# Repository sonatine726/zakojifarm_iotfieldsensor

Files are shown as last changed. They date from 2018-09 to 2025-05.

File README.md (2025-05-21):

# 座光寺農園の田んぼの環境センシングIoT機器

# 機能仕様

1. 設置した田んぼの気温、気圧、水位、GPS座標、バッテリー残量といったデータを定期的に計測する
2. 1で計測したデータをLTEでWEBサーバにアップロードする
3. 間欠動作でバッテリー交換無しで１シーズンの長期間駆動を実現する
4. 2のデータはWEBブラウザやスマートフォンアプリで、時系列順の参照や統計処理を可能にする
5. 4のデータに対してメールやMQTTによるアラート通知を可能にする
6. 自動水門開閉機能といった将来的な機能拡張が可能な機構や設計にする

# 成果物の形式と保管場所
## ハードウェア
### 機構
CADデータは Fusion360で作成。保管はFusion Team のクラウドストレージを使用する。
それ以外のデータは本リポジトリに保管。

### 基板
基板データはKiCadで作成。保管は本リポジトリ。

Pcbディレクトリ： 各基板のKiCadデータ

Fritzingディレクトリ： 試作用のFritzingデータ

## ソフトウェア
### クライアント(IoT機器)
本リポジトリに保管。

### サーバ
WEBサービスごとに専用のリポジトリを作って保管

### スマートフォンアプリ
アプリケーションごとに専用のリポジトリを作って保管

# 各成果物のイメージ
## 基板

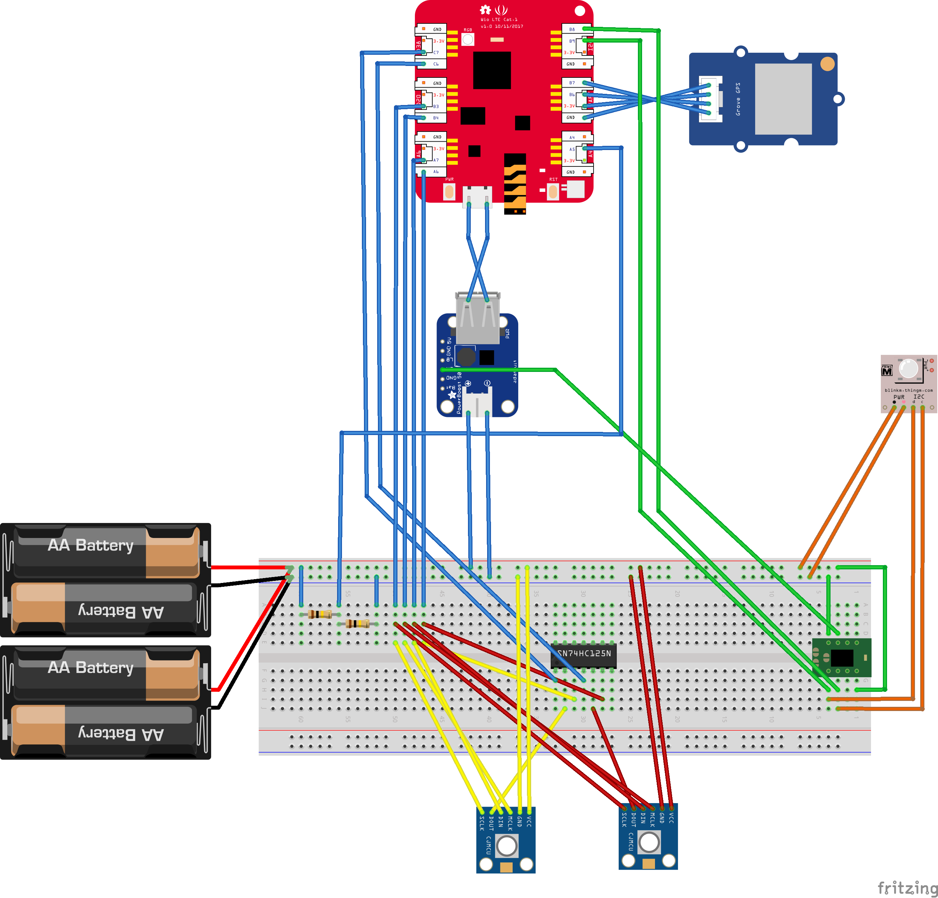
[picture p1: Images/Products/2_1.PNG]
試作回路

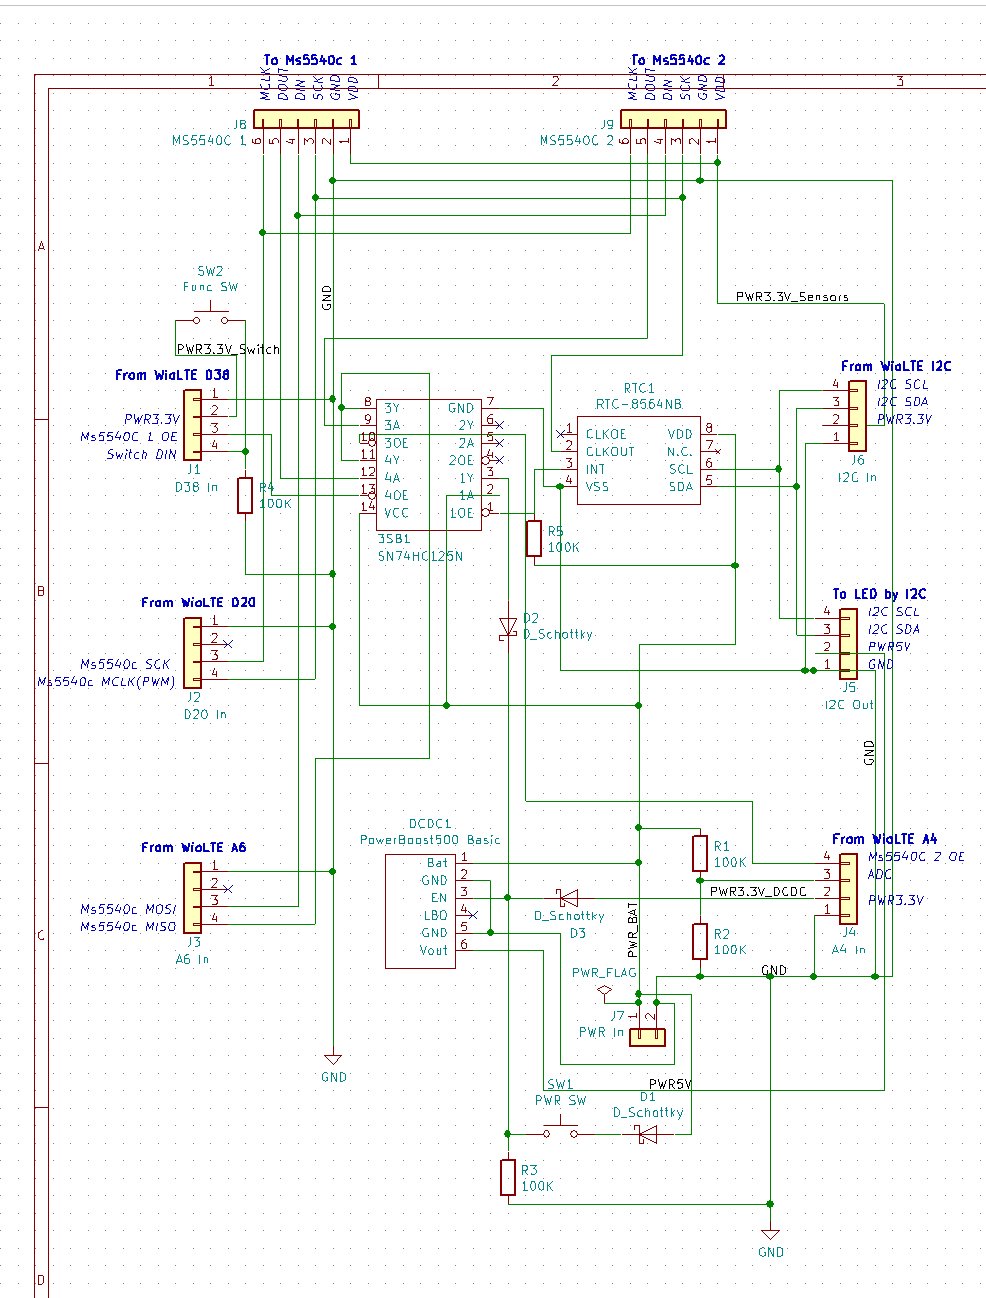
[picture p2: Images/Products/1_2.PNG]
回路基板

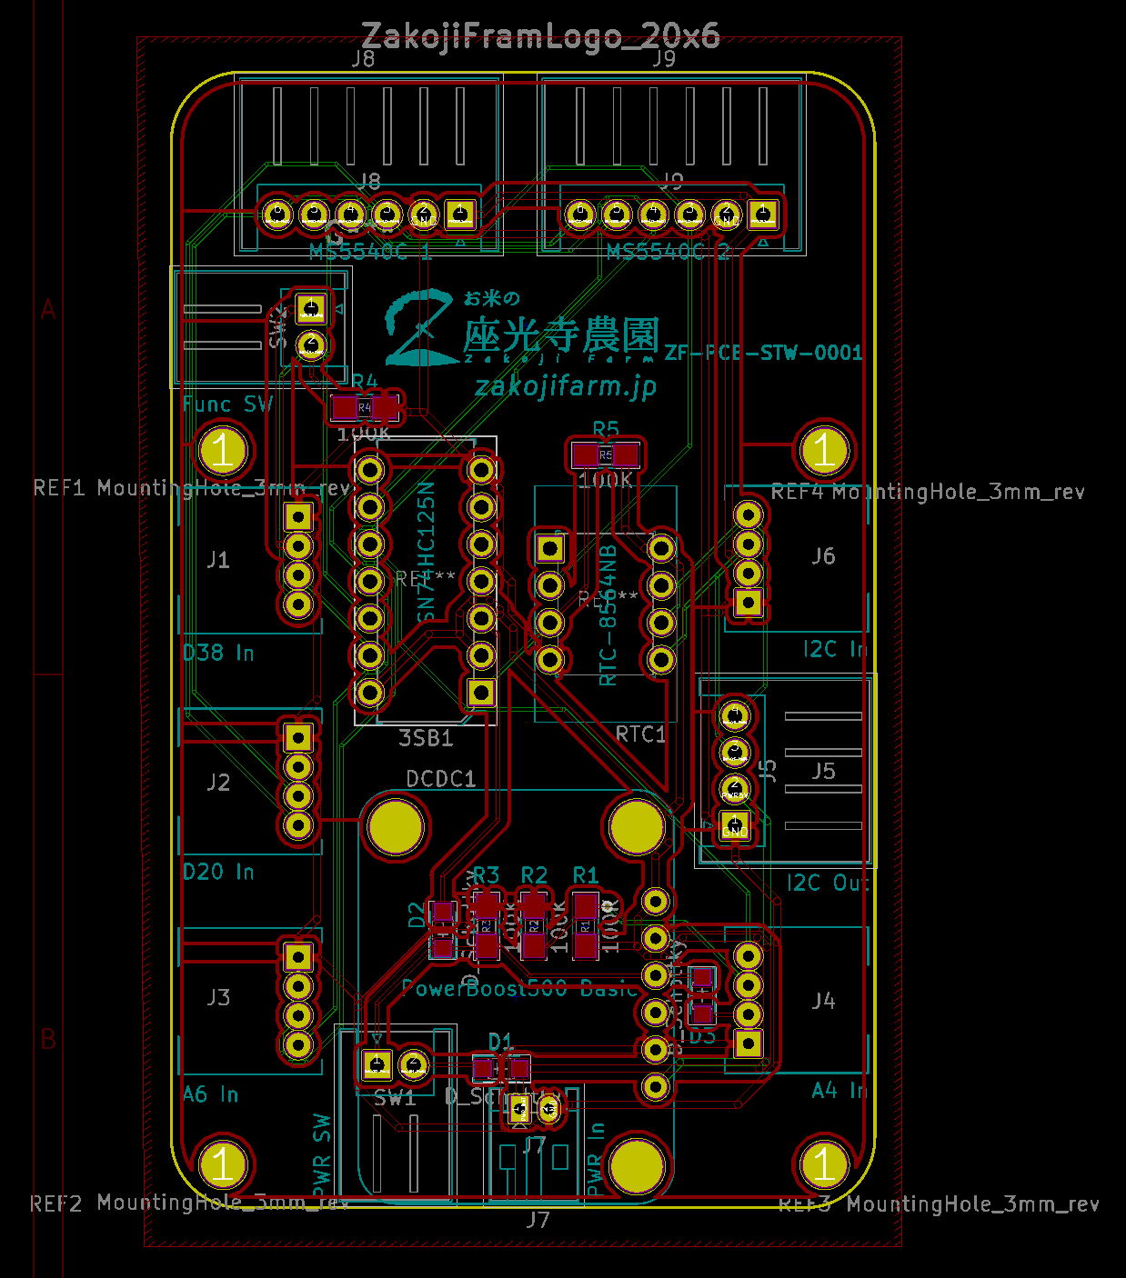
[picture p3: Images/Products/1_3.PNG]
アートワーク

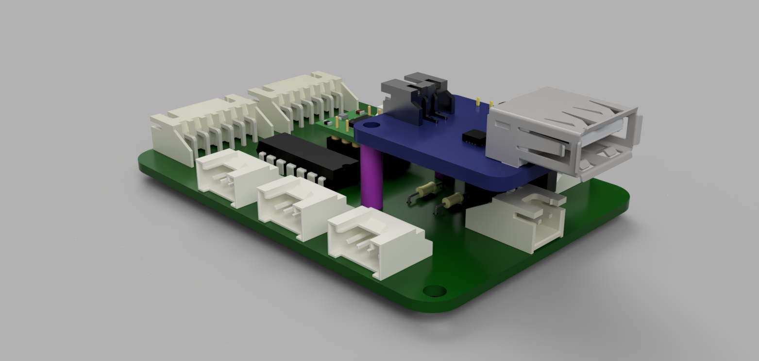
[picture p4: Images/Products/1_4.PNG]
CGイメージ

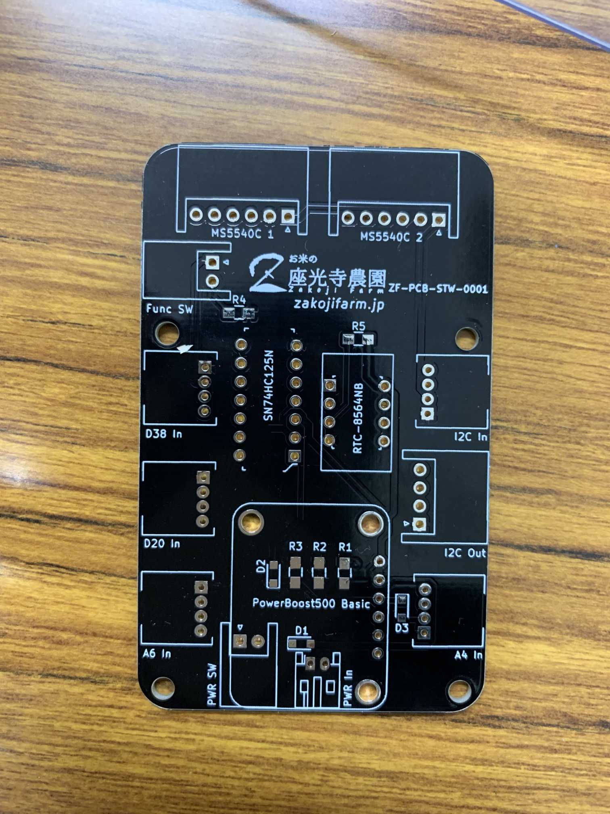
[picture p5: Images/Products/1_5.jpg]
成果物1

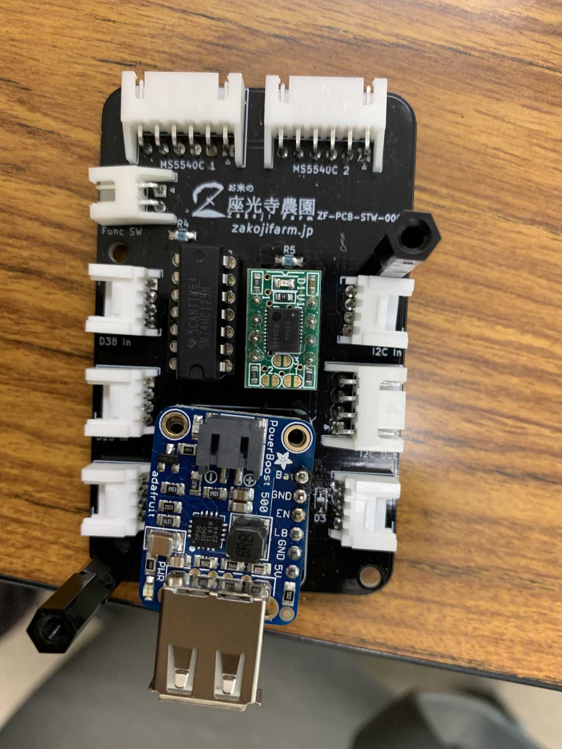
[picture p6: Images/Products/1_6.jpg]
成果物2


## 機構
### フラグシップモデル
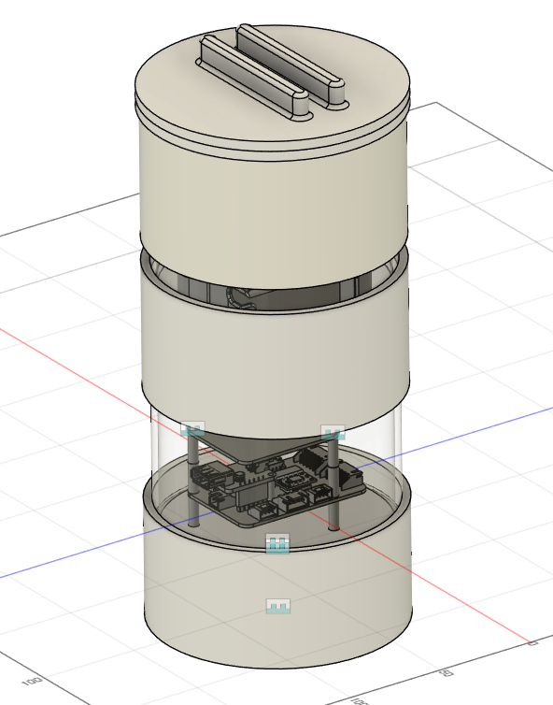
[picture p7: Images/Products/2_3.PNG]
機構1-1

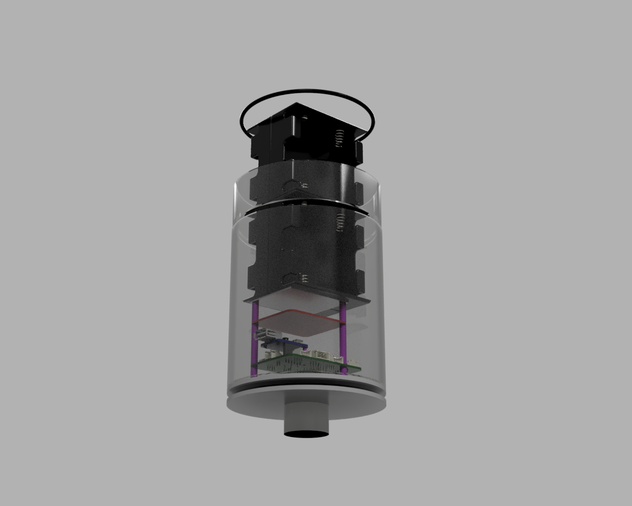
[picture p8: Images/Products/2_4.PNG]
機構1-2

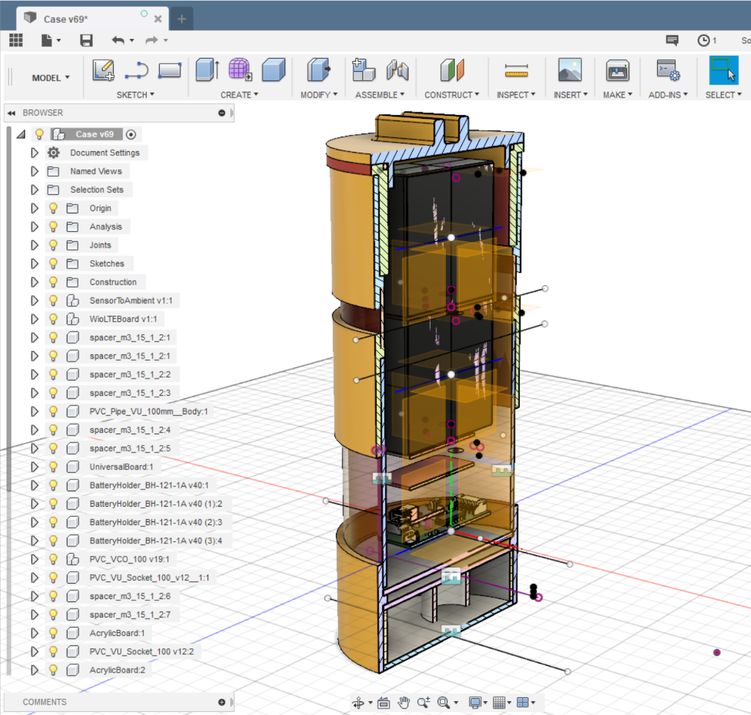
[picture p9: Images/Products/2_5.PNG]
機構1-3

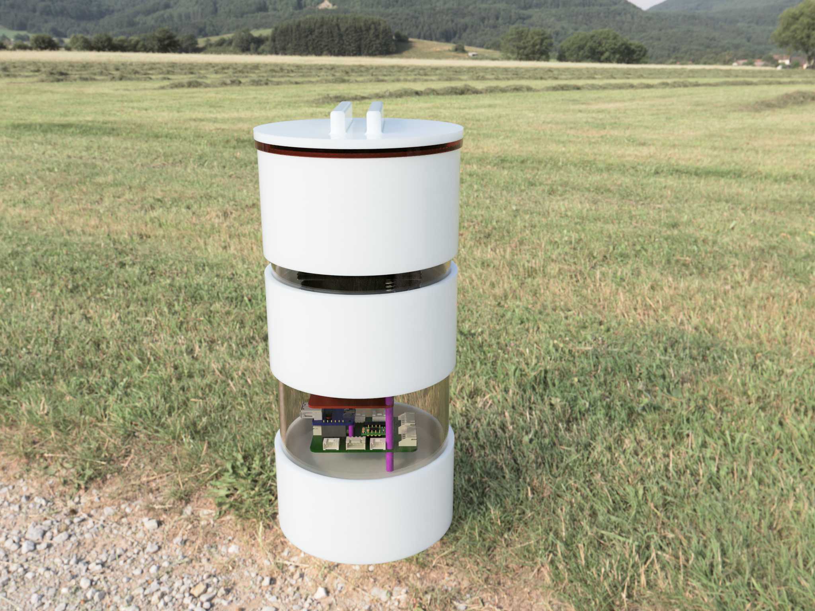
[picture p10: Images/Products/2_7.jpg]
機構1-4

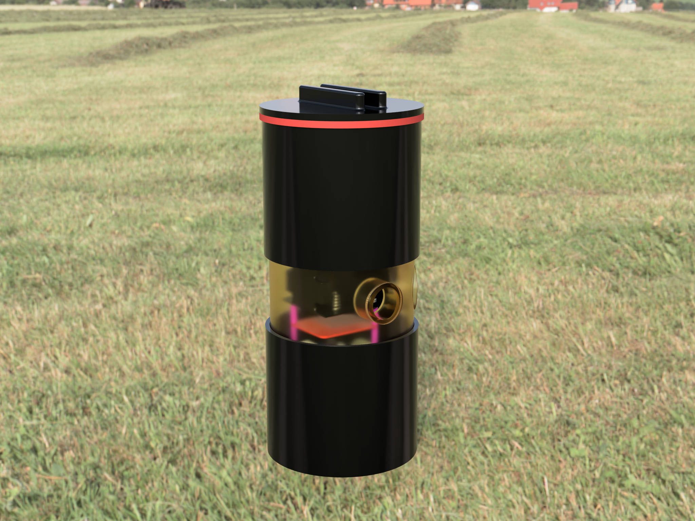
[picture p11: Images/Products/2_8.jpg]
機構1-5


### エントリーモデル
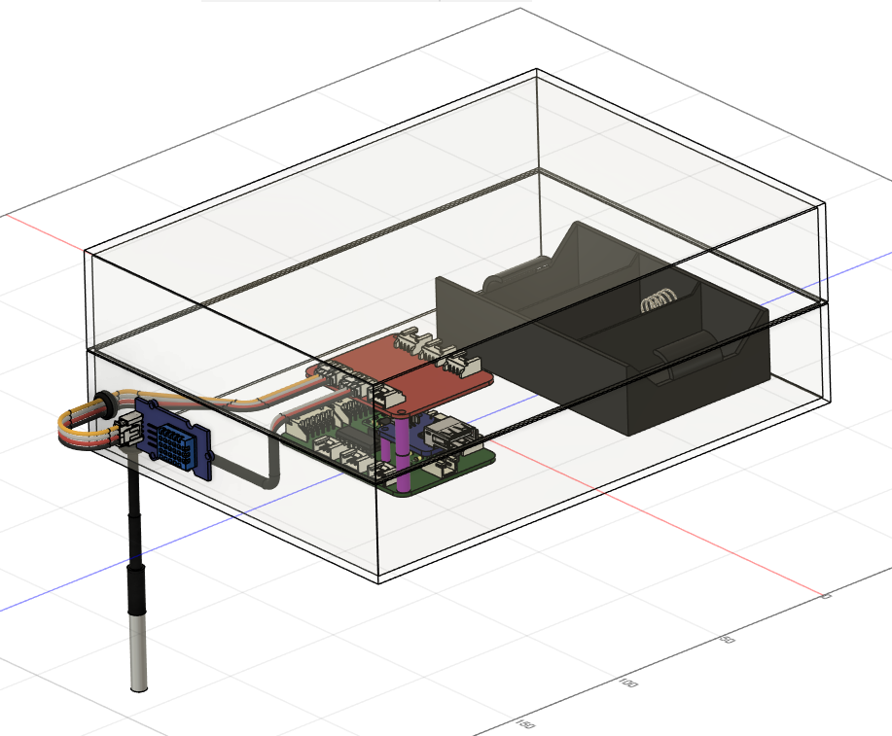
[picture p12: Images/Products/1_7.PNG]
機構2-1

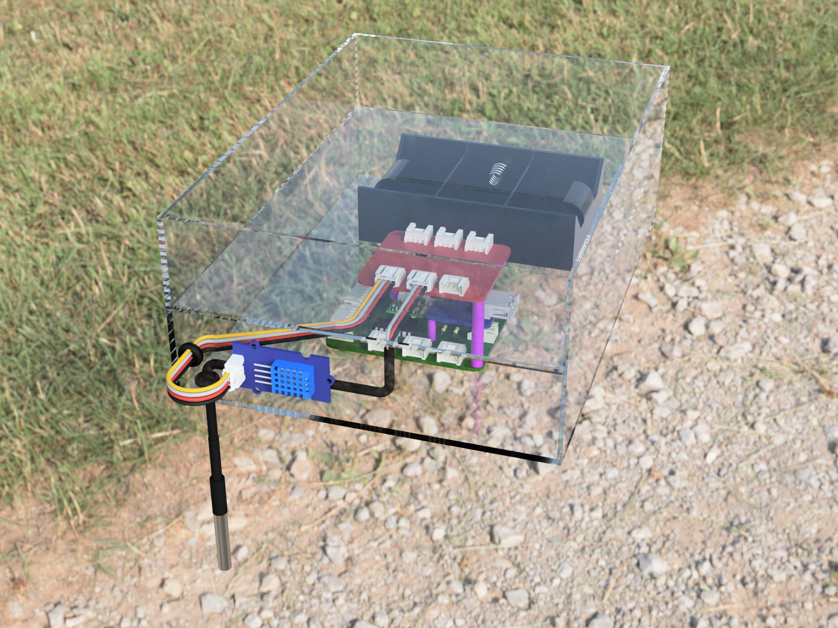
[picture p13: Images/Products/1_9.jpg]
機構2-2

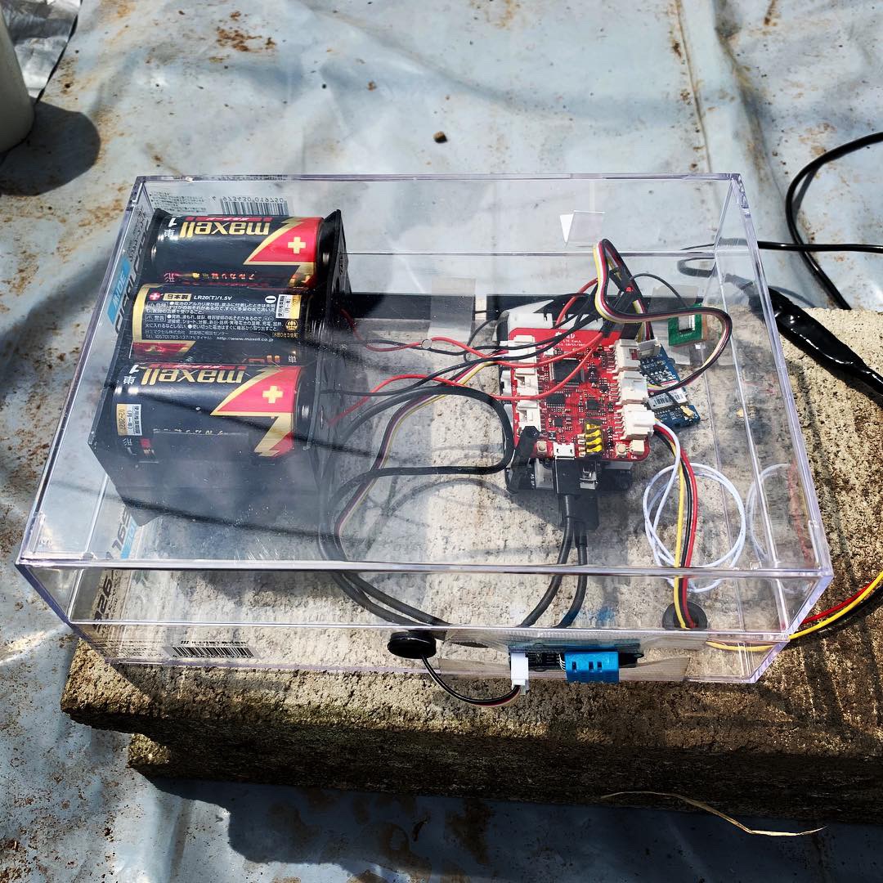
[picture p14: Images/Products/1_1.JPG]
機構2-3


## 作業風景
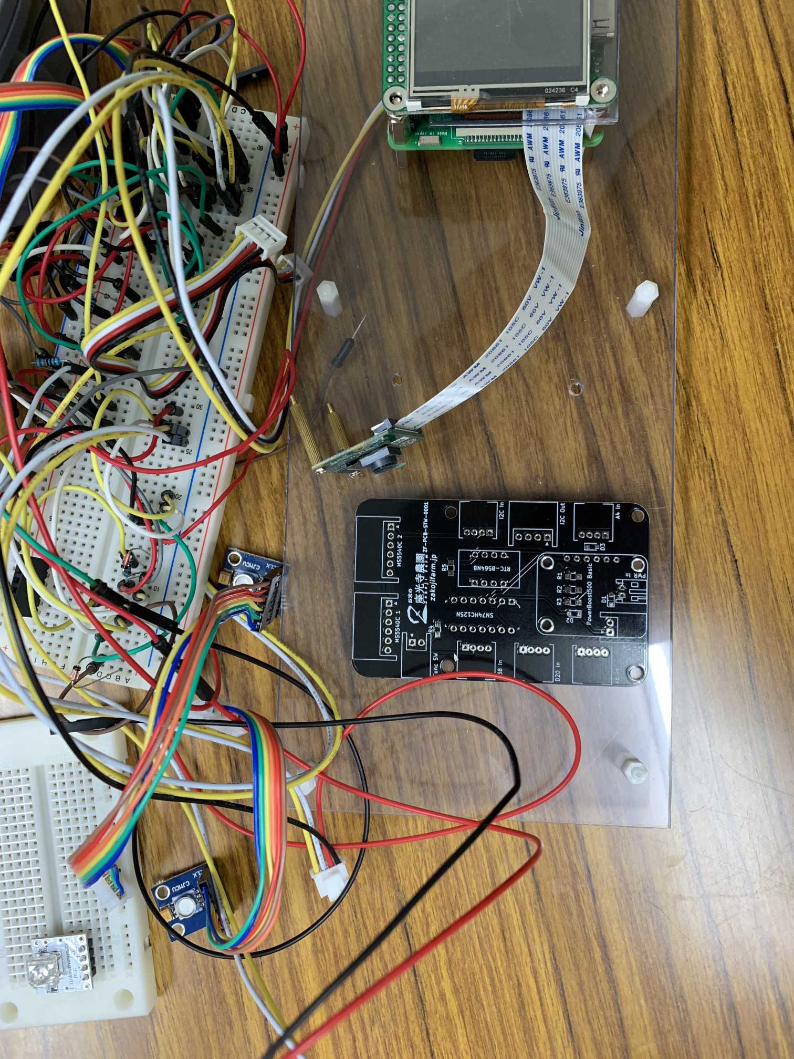
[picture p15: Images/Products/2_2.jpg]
作業風景1

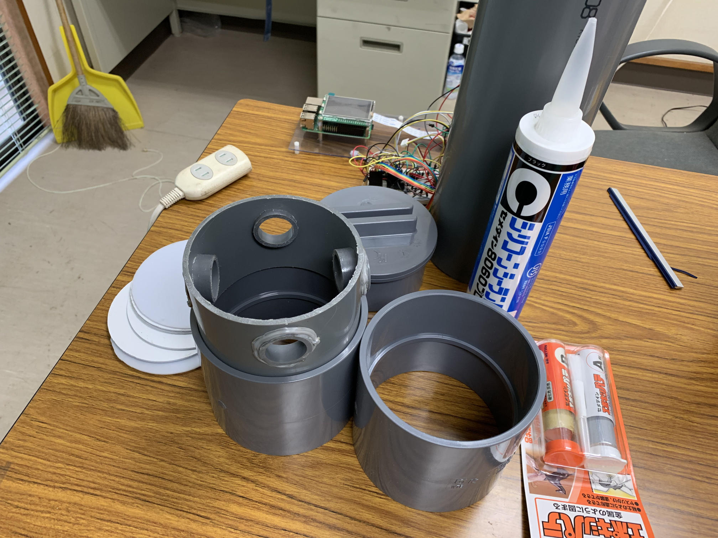
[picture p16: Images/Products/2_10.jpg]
作業風景2


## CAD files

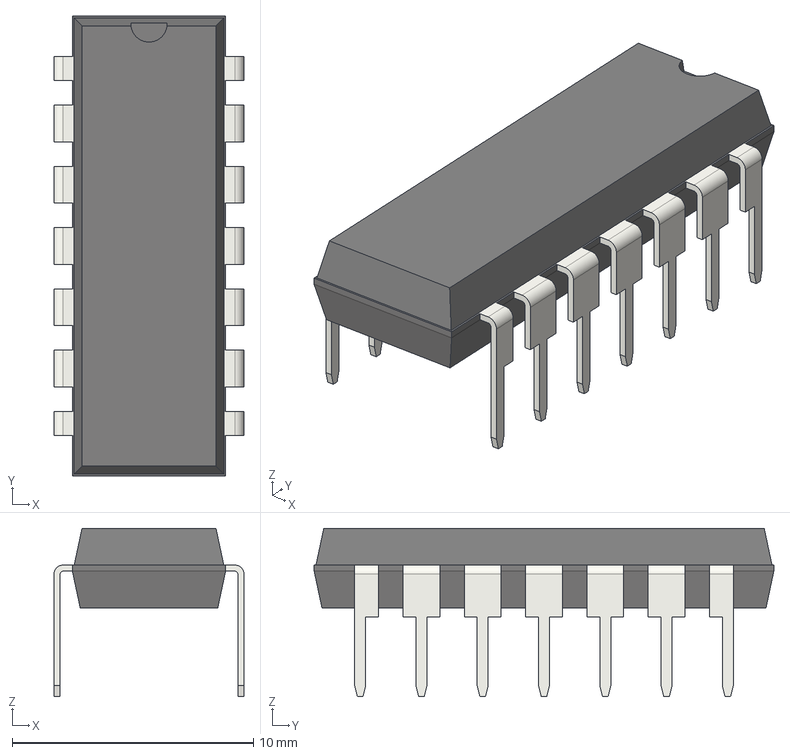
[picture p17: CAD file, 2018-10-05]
Pcb/SensorToAmbient/AdditionalParts/DIP-14_W7.62mm.step
7.87 x 19.1 x 6.98 mm

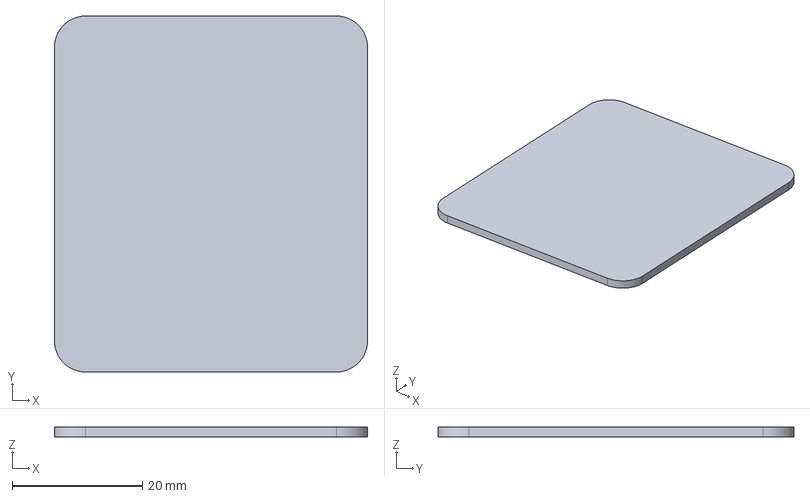
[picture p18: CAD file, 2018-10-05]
Pcb/SensorToAmbient/WioLTE.step
48.1 x 54.7 x 1.60 mm

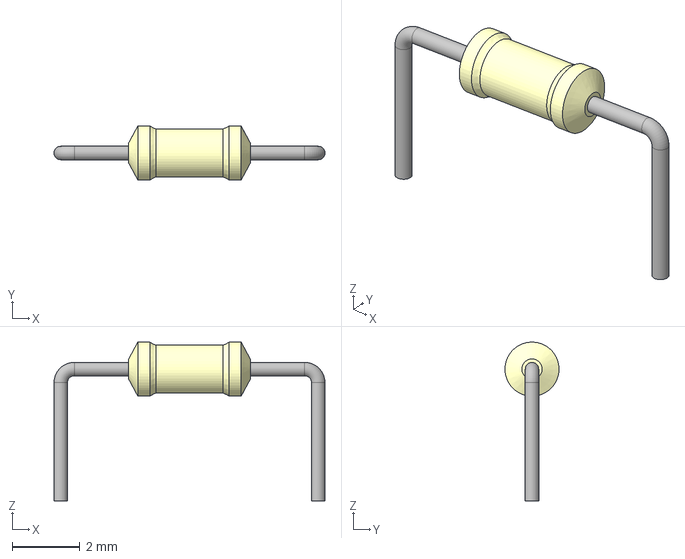
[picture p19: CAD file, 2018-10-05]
Pcb/SensorToAmbient/AdditionalParts/R_Axial_DIN0207_L6.3mm_D2.5mm_P7.62mm_Horizontal.step
8.02 x 1.60 x 4.70 mm

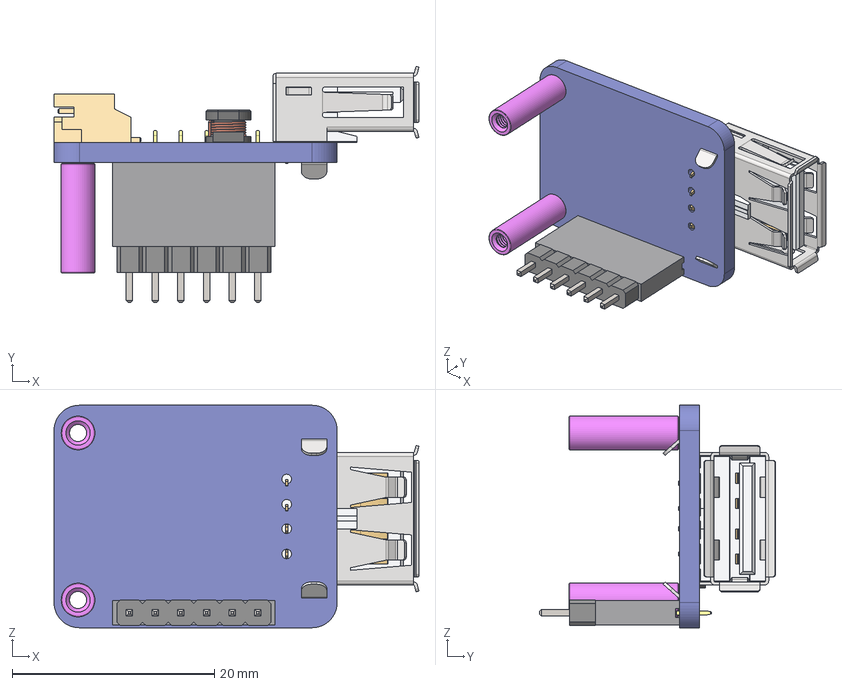
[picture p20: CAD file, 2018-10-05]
Pcb/SensorToAmbient/PowerBoost500.step
36.1 x 23.4 x 22.0 mm
S2B-PH-SM4-TB
Pinouts_Solid
Wire10
Wire9
Wire8
Wire7
Wire6
Wire5
Wire4
Wire3
Wire2
Wire1
Top_Chamfer_Solid
Foundation_Solid
femaleThruHoleUSB
spacer_m3_15 v1
spacer_m3_15 v1 (1)
QI_Connector_6pin_Female v1
pin_Predeterminado x 6
pin_body_Predeterminado
Board
Pads12-15
Pads5-8
Pads1-4
Pin_Index

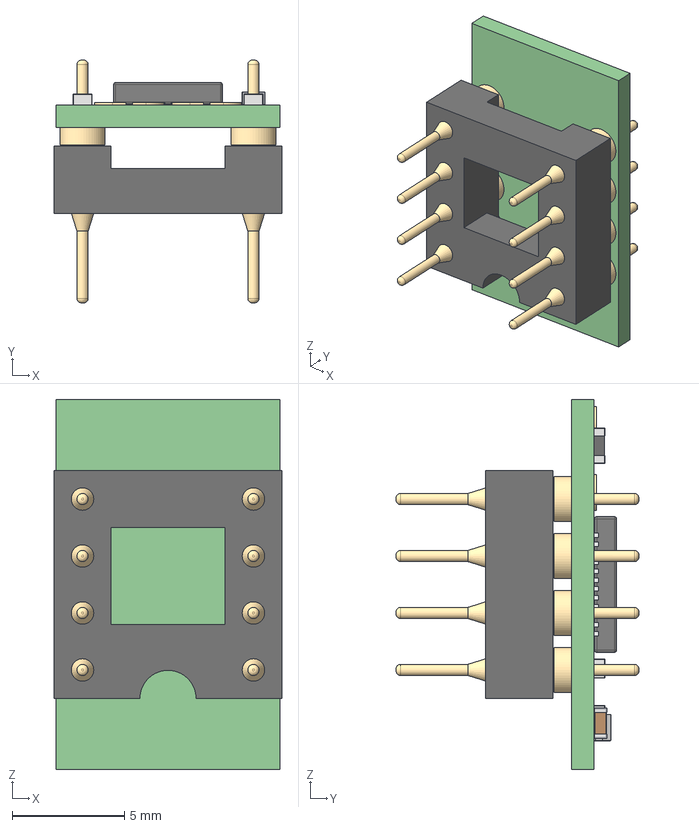
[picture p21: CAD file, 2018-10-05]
Pcb/SensorToAmbient/RTC-8564NB_Akidsuki.step
10.2 x 10.8 x 16.5 mm
RTC_8564NB v3
Resistor1608 v1
Resistor1608 v1 (1)
Resistor1608 v1 (2)
Resistor1608 v1 (3)
Capacitor1210 v3
chip_diode v3
Dip_socket_8pin

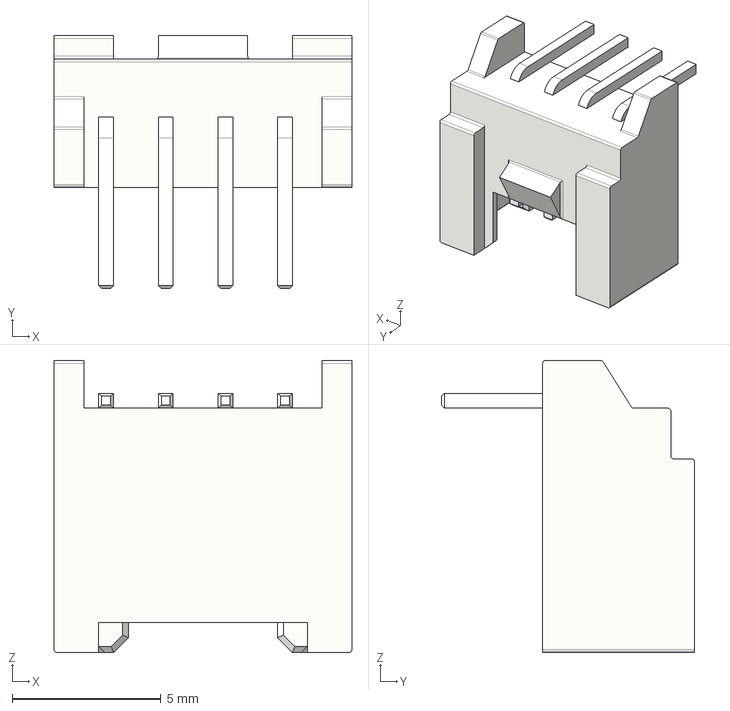
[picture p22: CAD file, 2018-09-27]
Pcb/SensorToAmbient/GroveConnector_110990037.step
10.0 x 8.50 x 9.80 mm

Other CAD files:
Pcb/SensorToAmbient/GroveConnector_110990037.f3d
Pcb/SensorToAmbient/RTC_8564NB_Akidsuki.f3d
Pcb/SensorToAmbient/WioLTEBoard.f3d

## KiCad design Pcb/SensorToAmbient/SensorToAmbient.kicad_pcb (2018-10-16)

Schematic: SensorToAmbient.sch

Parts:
3SB1: SN74HC125N; DIP-14_W3mm
D1, D2, D3: D_Schottky; D_SOD-323_HandSoldering
DCDC1: PowerBoost500 Basic; DCDC_PowerBoost500
J1: D38 In; Grove_2mm_4pin_angle2
J2: D20 In; Grove_2mm_4pin_angle2
J3: A6 In; Grove_2mm_4pin_angle2
J4: A4 In; Grove_2mm_4pin_angle2
J5: I2C Out; JST_XH_S04B-XH-A_04x2.50mm_Angled
J6: I2C In; Grove_2mm_4pin_angle2
J7: PWR In; JST_PH_S2B-PH-K_02x2.00mm_Angled
J8: MS5540C 1; JST_XH_S06B-XH-A_06x2.50mm_Angled
J9: MS5540C 2; JST_XH_S06B-XH-A_06x2.50mm_Angled
R1, R2, R3, R4, R5: 100K; R_0805_HandSoldering
RTC1: RTC-8564NB; RTC-8564NB_Akiduki
SW1: PWR SW; JST_XH_S02B-XH-A_02x2.50mm_Angled
SW2: Func SW; JST_XH_S02B-XH-A_02x2.50mm_Angled

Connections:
/PWR3.3V_DCDC: D3.2 (A), J4.2
/PWR3.3V_Sensors: J6.2, J8.1, J9.1
/PWR3.3V_Switch: J1.2, SW2.1
/PWR5V: DCDC1.6 (Vout), J5.2
/PWR_BAT: 3SB1.2 (1A), 3SB1.14 (VCC), D1.2 (A), DCDC1.1 (Bat), J7.1, R1.1, R5.2, RTC1.8 (VDD)
GND: 3SB1.7 (GND), DCDC1.2 (GND), DCDC1.5 (GND), J1.1, J2.1, J3.1, J4.1, J5.1, J6.1, J7.2, J8.2, J9.2, R2.2, R3.2, R4.2, RTC1.4 (VSS)
unnamed: 3SB1.1 (1OE), R5.1, RTC1.3 (INT)
unnamed: 3SB1.3 (1Y), D2.2 (A)
unnamed: 3SB1.9 (3A), J9.5
unnamed: 3SB1.10 (3OE), J4.4
unnamed: 3SB1.8 (3Y), 3SB1.11 (4Y), J3.4
unnamed: 3SB1.12 (4A), J8.5
unnamed: 3SB1.13 (4OE), J1.3
unnamed: D1.1 (K), SW1.2
unnamed: D2.1 (K), D3.1 (K), DCDC1.3 (EN), R3.1, SW1.1
unnamed: J1.4, R4.1, SW2.2
unnamed: J2.3, J8.6, J9.6
unnamed: J2.4, J8.3, J9.3, RTC1.2 (CLKOUT)
unnamed: J3.3, J8.4, J9.4
unnamed: J4.3, R1.2, R2.1
unnamed: J5.3, J6.3, RTC1.5 (SDA)
unnamed: J5.4, J6.4, RTC1.6 (SCL)

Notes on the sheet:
I2C SCL
I2C SDA
PWR3.3V
From WioLTE I2C
To LED by I2C
From WioLTE A4
From WioLTE D38
From WioLTE D20
From WioLTE A6
PWR5V
GND
ADC
To Ms5540c 2
To Ms5540c 1
Ms5540C 2 OE
Ms5540c MISO
Ms5540c MOSI
Ms5540c SCK
Ms5540c MCLK(PWM)
Switch DIN
Ms5540C 1 OE
MCLK
DOUT
DIN
SCK
VDD

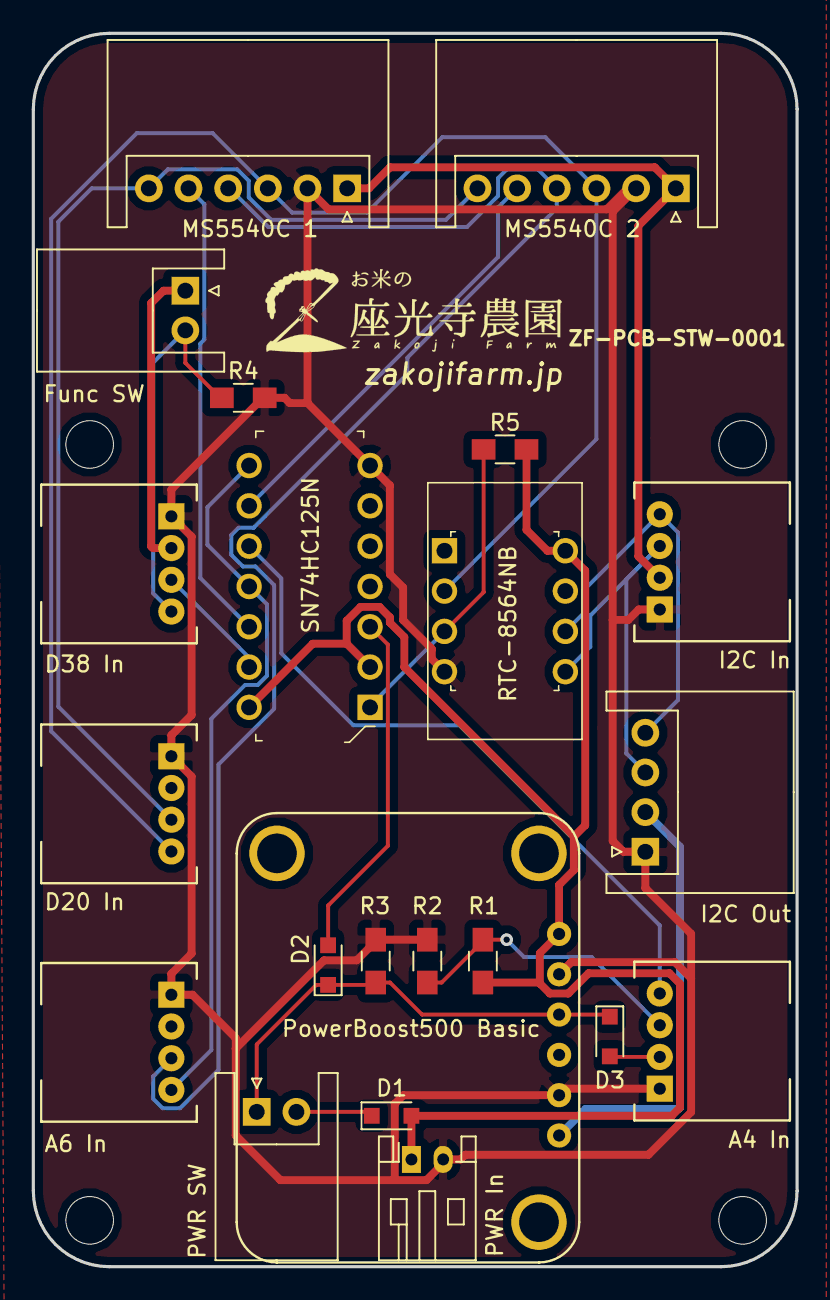
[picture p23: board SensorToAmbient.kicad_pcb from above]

Board: 2 copper layers, 48.1 x 77.7 mm, 26 parts (0 on the bottom side), 22 nets.

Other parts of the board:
REF1, REF2, REF3, REF4: MountingHole_3mm_rev

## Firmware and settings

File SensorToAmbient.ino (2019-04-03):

#include <stdlib.h>
#include <assert.h>

#include <WioLTEforArduino.h>
#include <WioLTEClient.h>
#include <TinyGPS++.h>
#include <RTClock.h>
#include <time.h>
#include <OneWire.h>
#include <DallasTemperature.h>
#include <Wire.h>
#include <HardwareTimer.h>
#include "Ms5540cSPI.h"
#include "StwI2c.h"

typedef int IRQn_Type;
#define __NVIC_PRIO_BITS          4
#define __Vendor_SysTickConfig    1
#include <libmaple/libmaple_types.h>
#include <libmaple/usbF4/VCP/core_cm4.h>
#include <libmaple/usbF4/VCP/core_cmInstr.h>
#include <libmaple/pwr.h>
#include "Ambient.h"

// Compile Switch
#define C_SW_LTE 1
#define C_SW_AMBIENT 1
#define C_SW_DHT11 0
#define C_SW_DS18B20 0
#define C_SW_GPS 1
#define C_SW_BATTERY_V 1
#define C_SW_MS5540C 1
#define C_SW_SLEEP_WAIT 1
#define C_SW_EXT_RTC 1
#define C_SW_MS5540C_ADC_CLOCK_BY_EXT_RTC 0
#define C_SW_SLEEP_BY_POWERDOWN 1
#define C_SW_LED_BLINKM 1


//Common global
#define SENSOR_PIN    (WIOLTE_D38)
#define LOOP_PERIOD_MSEC 60000 // milliseconds
#define SLEEP_MSEC_WHEN_OVER_LOOP_PERIOD 10000 // milliseconds

WioLTE Wio;
WioLTEClient WioClient(&Wio);

constexpr int LOG_TEMP_BUF_SIZE = 64;

RTClock rtc(RTCSEL_LSI);
constexpr time_t JAPAN_TIME_DIFF = 9 * 60 * 60; // UTC + 9h

// constexpr uint32* P_RTC_BKP0R = reinterpret_cast<uint32*>(RTC_BASE) + 0x50;

constexpr float INVALID_TEMP_AND_WATERLEVEL = -127;

constexpr uint8 I2C1_SCL_PIN = Port2Pin('B', 8);
constexpr uint8 I2C1_SDA_PIN = Port2Pin('B', 9);

bool isSuccessSetup;

#if C_SW_LTE
//LTE global
#define APN       "soracom.io"
#define USERNAME  "sora"
#define PASSWORD  "sora"
#endif //C_SW_LTE

#if C_SW_AMBIENT
//Ambient global
//Test ID Parameters
unsigned int AMBIENT_CHANNEL_ID = 6359;
const char AMBIENT_WRITE_KEY[] = "12ad25a29e628a86";
Ambient ambient;
#endif //C_SW_AMBIENT

constexpr double INVALID_GPS_VALUE = -1;
#if C_SW_GPS
//GPS global
HardwareSerial* GpsSerial;
TinyGPSPlus gps;
#endif //C_SW_GPS

//NTP
const char NTP_SERVER[] = "ntp.nict.jp";

#if C_SW_DS18B20
//DS18B20
OneWire oneWire(WIOLTE_A4);
DallasTemperature dS18b20(&oneWire);
constexpr uint8_t DS18B20_TEMPERATURE_RESOLUTION_BIT = 12;

#endif //C_SW_DS18B20

TwoWire i2c;

#if C_SW_EXT_RTC
constexpr uint8 RTC_I2C_ADDR = 0x51;

constexpr uint8 RTC_REG_CTR1 = 0x00;
constexpr uint8 RTC_REG_CTR2 = 0x01;
constexpr uint8 RTC_REG_SEC = 0x02;
constexpr uint8 RTC_REG_MIN = 0x03;
constexpr uint8 RTC_REG_HOUR = 0x04;
constexpr uint8 RTC_REG_DAYS = 0x05;
constexpr uint8 RTC_REG_WEEK = 0x06;
constexpr uint8 RTC_REG_MONTH = 0x07;
constexpr uint8 RTC_REG_YEAR = 0x08;
constexpr uint8 RTC_REG_MIN_ALR = 0x09;
constexpr uint8 RTC_REG_HOUR_ALR = 0x0A;
constexpr uint8 RTC_REG_DAY_ALR = 0x0B;
constexpr uint8 RTC_REG_WEEK_ALR = 0x0C;
constexpr uint8 RTC_REG_CLKO_FREQ = 0x0D;
constexpr uint8 RTC_REG_TIMER_CTR = 0x0E;
constexpr uint8 RTC_REG_TIMER = 0x0F;

#endif //C_SW_EXT_RTC


#if C_SW_MS5540C
constexpr uint8 ADC_CLOCK_PIN_FOR_MS5540C = Port2Pin('B', 4); // D20;
constexpr uint8 OE_PIN_FOR_MS5540C_AIR = Port2Pin('A', 4); // D4;
constexpr uint8 OE_PIN_FOR_MS5540C_WATER = Port2Pin('C', 7); // D39;

Ms5540cSPI ms5540cSpi(1);

enum MS5540C_SENSOR_ID
{
	MS5540C_AIR,
	MS5540C_WATER,
	MS5540C_SENSOR_NUMBER
};

uint32 ms5540c_c1[MS5540C_SENSOR_NUMBER];
uint32 ms5540c_c2[MS5540C_SENSOR_NUMBER];
uint32 ms5540c_c3[MS5540C_SENSOR_NUMBER];
uint32 ms5540c_c4[MS5540C_SENSOR_NUMBER];
uint32 ms5540c_c5[MS5540C_SENSOR_NUMBER];
uint32 ms5540c_c6[MS5540C_SENSOR_NUMBER];
#endif //C_SW_MS5540C


#if C_SW_BATTERY_V
constexpr unsigned int EXTERNAL_BATTERY_ADC_PIN = Port2Pin('A', 5);
constexpr unsigned int INTERNAL_BATTERY_ADC_CHANNEL = 18;
constexpr unsigned int INTERNAL_TEMPERATURE_ADC_CHANNEL = 16;
#endif //C_SW_BATTERY_V

#if C_SW_LED_BLINKM
constexpr uint8 LED_I2C_ADDR = 0x09;

constexpr uint8 LED_R_FOR_SETUP = 0;
constexpr uint8 LED_G_FOR_SETUP = 255;
constexpr uint8 LED_B_FOR_SETUP = 255;
constexpr uint8 FADE_SPEED_FOR_SETUP_LED = 15;

constexpr uint8 LED_R_FOR_GET_SENSORS = 255;
constexpr uint8 LED_G_FOR_GET_SENSORS = 255;
constexpr uint8 LED_B_FOR_GET_SENSORS = 0;
constexpr uint8 FADE_SPEED_FOR_GET_SENSORS_LED = 15;

constexpr uint8 LED_R_FOR_SEND_TO_SERVER = 0;
constexpr uint8 LED_G_FOR_SEND_TO_SERVER = 255;
constexpr uint8 LED_B_FOR_SEND_TO_SERVER = 0;
constexpr uint8 FADE_SPEED_FOR_SEND_TO_SERVER = 15;

constexpr uint8 LED_R_FOR_SUCCESS = 0;
constexpr uint8 LED_G_FOR_SUCCESS = 0;
constexpr uint8 LED_B_FOR_SUCCESS = 255;
constexpr uint8 FADE_SPEED_FOR_SUCCESS = 15;

constexpr uint8 ERROR_ALERT_LED_R = 255;
constexpr uint8 ERROR_ALERT_LED_G = 0;
constexpr uint8 ERROR_ALERT_LED_B = 0;
constexpr uint8 ERROR_ALERT_LED_FADE_SPEED = 15;
constexpr uint8 ERROR_ALERT_LED_DURATION_MSEC = 15000;

constexpr uint8 ERROR_BLINK_LED_R = 255;
constexpr uint8 ERROR_BLINK_LED_G = 0;
constexpr uint8 ERROR_BLINK_LED_B = 0;
constexpr uint8 ERROR_BLINK_LED_FADE_SPEED = 15;
constexpr uint8 ERROR_BLINK_LED_DURATION_MSEC = 1000;
constexpr uint8 ERROR_BLINK_LED_INTERVAL_MSEC = 500;

constexpr uint8 ERROR_BLINK_LED_COUNT_FOR_LOWBATTERY = 1;
constexpr uint8 ERROR_BLINK_LED_COUNT_FOR_LTE = 2;
constexpr uint8 ERROR_BLINK_LED_COUNT_FOR_PWM = 8;
constexpr uint8 ERROR_BLINK_LED_COUNT_FOR_NTP = 10;
constexpr uint8 ERROR_BLINK_LED_COUNT_FOR_EXT_RTC_SET_ALARM = 5;
constexpr uint8 ERROR_BLINK_LED_COUNT_FOR_EXT_RTC_INIT = 6;
constexpr uint8 ERROR_BLINK_LED_COUNT_FOR_EXT_RTC_SET_TIME = 7;
constexpr uint8 ERROR_BLINK_LED_COUNT_FOR_EXT_RTC_OTHERS = 9;
constexpr uint8 ERROR_BLINK_LED_COUNT_FOR_CONNECT_AMBIENT = 3;
constexpr uint8 ERROR_BLINK_LED_COUNT_FOR_INIT_MS5540C = 8;
constexpr uint8 ERROR_BLINK_LED_COUNT_FOR_SEND_TO_AMBIENT = 4;
constexpr uint8 ERROR_BLINK_LED_COUNT_FOR_OTHERS = 15;



#endif //C_SW_LED_BLINKM

void setup()
{
	isSuccessSetup = false;

	Wio.Init();

	SerialUSB.println("INFO: setup()");

	Wio.PowerSupplyGrove(true);

	i2c.begin();

	//Wait for i2c ready
	delay(500);

#if C_SW_LED_BLINKM
	if (!FadeLedToSetupColor())
	{
		SerialUSB.println("ERROR: FadeLedToSetupColor");
		//Continue setup because led failure isn't critical
	}

	//Set starup parameters to stop default script for factory shipment LED
	if (!StopStartupScriptAtExtLed())
	{
		SerialUSB.println("ERROR: StopStartupScriptAtExtLed");
		//Continue setup because led failure isn't critical
	}
#endif //C_SW_LED_BLINKM

#if C_SW_EXT_RTC
	if (!InitializeExtRtc())
	{
		SerialUSB.println("ERROR: InitializeExtRtc");
		//Continue setup because external RTC setup can be made up for by subsequent processing
	}
#endif //C_SW_EXT_RTC

#if C_SW_LTE
	//Setup LTE
	SerialUSB.println("INFO: Setup LTE");
	if (!SetupLTE())
	{
		SerialUSB.println("ERROR: SetupLTE");
		BlinkErrorLight(ERROR_BLINK_LED_COUNT_FOR_LTE);
		return;
	}

	if (!UpdateRtcByNtp())
	{
		SerialUSB.println("ERROR: UpdateRtcByNtp");
		BlinkErrorLight(ERROR_BLINK_LED_COUNT_FOR_NTP);
		//Continue setup because NTP failure isn't critical
	}

#if C_SW_EXT_RTC
	struct tm current_time = { 0 };
	rtc.getTime(&current_time);

	if (!SetExtRtcTime(current_time))
	{
		SerialUSB.println("ERROR: SetExtRtcTime");
		BlinkErrorLight(ERROR_BLINK_LED_COUNT_FOR_EXT_RTC_SET_TIME);
		//Continue setup because RTC failure isn't critical
	}
#endif //C_SW_EXT_RTC

#if C_SW_AMBIENT
	//Setup Ambient
	SerialUSB.println("INFO: Setup Ambient");
	if (!ambient.begin(AMBIENT_CHANNEL_ID, AMBIENT_WRITE_KEY, &WioClient))
	{
		SerialUSB.println("ERROR: Ambient::begin");
		BlinkErrorLight(ERROR_BLINK_LED_COUNT_FOR_CONNECT_AMBIENT);
		return;
	}
#endif //C_SW_AMBIENT

#else //C_SW_LTE
	delay(500);
#endif //C_SW_LTE

#if C_SW_DHT11
	//Setup DHT11
	SerialUSB.println("INFO: Setup DHT11");
	TemperatureAndHumidityBegin(SENSOR_PIN);
#endif //C_SW_DHT11

#if C_SW_DS18B20
	//Setup DS18B20
	SerialUSB.println("INFO: SetupDS18B20");
	SetupDS18B20();
#endif //C_SW_DS18B20

#if C_SW_MS5540C
	if (!SetupMs5540c())
	{
		SerialUSB.println("ERROR: SetupMs5540c");
		BlinkErrorLight(ERROR_BLINK_LED_COUNT_FOR_INIT_MS5540C);
		return;
	}
#endif //C_SW_MS5540C

#if C_SW_BATTERY_V
	SetupADC();
#endif //C_SW_BATTERY_V

#if C_SW_GPS
	//Setup GPS
	GpsBegin(&Serial);
	delay(500);
#endif

	isSuccessSetup = true;
}

void loop()
{
	char cbuf[64] = { 0 };
	struct tm current_time = { 0 };
	rtc.getTime(&current_time);
	snprintf(cbuf, sizeof(cbuf), "loop() : %s", asctime(&current_time));
	SerialUSB.println(cbuf);

	if (isSuccessSetup)
	{
		if (!FadeLedToGetSensorsColor())
		{
			SerialUSB.println("ERROR: FadeLedToGetSensorsColor");
			BlinkErrorLight(ERROR_BLINK_LED_COUNT_FOR_OTHERS);
			//Continue funtions because LED failure isn't critical
		}

		/* Get temperature and humidity */
		float temp = INVALID_TEMP_AND_WATERLEVEL;
		float humi = INVALID_TEMP_AND_WATERLEVEL;

#if C_SW_DHT11
		SerialUSB.println("INFO: TemperatureAndHumidityRead()");
		if (TemperatureAndHumidityRead(&temp, &humi))
		{
			snprintf(cbuf, sizeof(cbuf), "INFO: humid = %f%%, temp = %f C", humi, temp);
			SerialUSB.println(cbuf);
		}
		else
		{
			SerialUSB.println("ERROR: TemperatureAndHumidityRead");
		}
#endif //C_SW_DHT11

		float tempDs18b20 = INVALID_TEMP_AND_WATERLEVEL;
#if C_SW_DS18B20
		/* Get water temperature from DS18B20 */
		SerialUSB.println("INFO: Get DS18B20 Temperature");
		tempDs18b20 = GetTemperatureDS18B20();
		snprintf(cbuf, sizeof(cbuf), "INFO: DS18B20 temp: %f", tempDs18b20);
		SerialUSB.println(cbuf);
#endif //C_SW_DS18B20

		float press_ms5540c[MS5540C_SENSOR_NUMBER] = { 0 };
		float temp_ms5540c[MS5540C_SENSOR_NUMBER] = { INVALID_TEMP_AND_WATERLEVEL };
		float water_level_cm = INVALID_TEMP_AND_WATERLEVEL;
#if C_SW_MS5540C
		for (int i = 0; i < MS5540C_SENSOR_NUMBER; ++i)
		{
			GetPressureAndTemperatureFromMs5540c(static_cast<MS5540C_SENSOR_ID>(i), press_ms5540c[i], temp_ms5540c[i]);
			snprintf(cbuf, sizeof(cbuf), "INFO: MS5540C[%d] press = %f mbar, temp = %f C", i, press_ms5540c[i], temp_ms5540c[i]);
			SerialUSB.println(cbuf);
		}

		water_level_cm = CalculateWaterLevelCm(press_ms5540c[MS5540C_WATER], press_ms5540c[MS5540C_AIR]);
		snprintf(cbuf, sizeof(cbuf), "INFO: Water level = %f cm", water_level_cm);
		SerialUSB.println(cbuf);
#endif //C_SW_MS5540C

		bool validGps = false;
		double lat, lng, meter;
#if C_SW_GPS
		/* Get GPS */
		SerialUSB.println("INFO: GpsRead()");
		validGps = GpsRead(lat, lng, meter);
		if (validGps)
		{
			SerialUSB.println("GPS Value:");
			snprintf(cbuf, sizeof(cbuf), "lat: %12.8f", lat);
			SerialUSB.println(cbuf);

			snprintf(cbuf, sizeof(cbuf), "lng: %12.8f", lng);
			SerialUSB.println(cbuf);

			snprintf(cbuf, sizeof(cbuf), "meter: %4.2f", meter);
			SerialUSB.println(cbuf);
		}
#endif //C_SW_GPS

		float ext_battery_v = 0;
		float in_battery_v = 0;
		float in_temperature = 0;
#if C_SW_BATTERY_V
		ext_battery_v = GetExternalBatteryV();
		snprintf(cbuf, sizeof(cbuf), "INFO: External Battery V %f mV", ext_battery_v);
		SerialUSB.println(cbuf);

		in_battery_v = GetInternalBatteryV();
		snprintf(cbuf, sizeof(cbuf), "INFO: Internal Battery V %f mV", in_battery_v);
		SerialUSB.println(cbuf);

		in_temperature = GetInternalTemperature();
		snprintf(cbuf, sizeof(cbuf), "INFO: Internal Temp %f", in_temperature);
		SerialUSB.println(cbuf);
#endif //C_SW_BATTERY_V

#if C_SW_LTE && C_SW_AMBIENT
		/* Send to Ambient */
		SerialUSB.println("INFO: SendToAmbient()");
		if (!FadeLedToSendToServerColor())
		{
			SerialUSB.println("ERROR: FadeLedToSendToServerColor");
			BlinkErrorLight(ERROR_BLINK_LED_COUNT_FOR_OTHERS);
			//Continue funtions because LED failure isn't critical
		}

		bool isSendSuccess;
		if (validGps)
		{
			isSendSuccess = SendToAmbient(press_ms5540c[MS5540C_WATER], temp_ms5540c[MS5540C_WATER], press_ms5540c[MS5540C_AIR], temp_ms5540c[MS5540C_AIR], water_level_cm, ext_battery_v, in_battery_v, in_temperature, lat, lng, meter);
		}
		else
		{
			isSendSuccess = SendToAmbient(press_ms5540c[MS5540C_WATER], temp_ms5540c[MS5540C_WATER], press_ms5540c[MS5540C_AIR], temp_ms5540c[MS5540C_AIR], water_level_cm, ext_battery_v, in_battery_v, in_temperature);
		}

		if (isSendSuccess)
		{
			if (!FadeLedToSuccessColor())
			{
				SerialUSB.println("ERROR: FadeLedToSuccessColor");
				BlinkErrorLight(ERROR_BLINK_LED_COUNT_FOR_OTHERS);
				//Continue funtions because LED failure isn't critical
			}
		}
		else
		{
			SerialUSB.println("ERROR: SendToAmbient");
			BlinkErrorLight(ERROR_BLINK_LED_COUNT_FOR_SEND_TO_AMBIENT);
		}
#endif //C_SW_LTE && C_SW_AMBIENT
	}
	else
	{
		SerialUSB.println("ERROR: Skip loop because of setup failure");
		if (!AlertErrorWithLed())
		{
			SerialUSB.println("ERROR: AlertErrorWithLed");
		}
	}

	/* Wait next loop */
	unsigned long elapse = millis();
	snprintf(cbuf, sizeof(cbuf), "Run elapse: %ld msec", elapse);
	SerialUSB.println(cbuf);

#if C_SW_SLEEP_WAIT
	time_t waittime_sec = 0;
	if (LOOP_PERIOD_MSEC > elapse)
	{
		waittime_sec = (LOOP_PERIOD_MSEC - elapse) / 1000;
	}
	else
	{
		waittime_sec = SLEEP_MSEC_WHEN_OVER_LOOP_PERIOD / 1000;
	}

	snprintf(cbuf, sizeof(cbuf), "Wait next loop: %ld sec", waittime_sec);
	SerialUSB.println(cbuf);

#if C_SW_LTE
	ShutdownLTE();
#endif //C_SW_LTE

	SleepUntilNextLoop(waittime_sec);
#else //C_SW_SLEEP_WAIT
	delay(LOOP_PERIOD_MSEC);
#endif //C_SW_SLEEP_WAIT
}

#if C_SW_LTE
//LTE functions
bool SetupLTE()
{
	Wio.PowerSupplyLTE(true);
	delay(500);

	if (!Wio.TurnOnOrReset())
	{
		SerialUSB.println("ERROR: Wio.TurnOnOrReset");
		return false;
	}

	if (!Wio.Activate(APN, USERNAME, PASSWORD))
	{
		SerialUSB.println("ERROR: Wio.Activate");
		return false;
	}

	return true;
}


void ShutdownLTE()
{
	Wio.Deactivate();  // Deactivate a PDP context. Added at v1.1.9
	Wio.TurnOff(); // Shutdown the LTE module. Added at v1.1.6
	Wio.PowerSupplyLTE(false); // Turn the power supply to LTE module off
}
#endif //C_SW_LTE


#if C_SW_DHT11
//Temperature and humidity functions
int TemperatureAndHumidityPin;

void TemperatureAndHumidityBegin(int pin)
{
	TemperatureAndHumidityPin = pin;
	DHT11Init(TemperatureAndHumidityPin);
}

bool TemperatureAndHumidityRead(float* temperature, float* humidity)
{
	byte data[5] = { 0 };

	DHT11Start(TemperatureAndHumidityPin);
	for (int i = 0; i < 5; i++)
	{
		data[i] = DHT11ReadByte(TemperatureAndHumidityPin);
	}
	DHT11Finish(TemperatureAndHumidityPin);

	if (!DHT11Check(data))
	{
		return false;
	}

	*humidity = (float)data[0] + (float)data[1] / 10.0f;
	*temperature = (float)data[2] + (float)data[3] / 10.0f;

	return true;
}

void DHT11Init(int pin)
{
	digitalWrite(pin, HIGH);
	pinMode(pin, OUTPUT);
}

void DHT11Start(int pin)
{
	// Host the start of signal
	digitalWrite(pin, LOW);
	delay(18);

	// Pulled up to wait for
	pinMode(pin, INPUT);
	while (!digitalRead(pin));

	// Response signal
	while (digitalRead(pin));

	// Pulled ready to output
	while (!digitalRead(pin));
}

byte DHT11ReadByte(int pin)
{
	byte data = 0;

	for (int i = 0; i < 8; i++)
	{
		while (digitalRead(pin));

		while (!digitalRead(pin));
		unsigned long start = micros();

		while (digitalRead(pin));
		unsigned long finish = micros();

		if ((unsigned long)(finish - start) > 50)
		{
			data |= 1 << (7 - i);
		}
	}

	return data;
}

void DHT11Finish(int pin)
{
	while (!digitalRead(pin));
	digitalWrite(pin, HIGH);
	pinMode(pin, OUTPUT);
}

bool DHT11Check(const byte data[5])
{
	byte sum = 0;
	for (int i = 0; i < 4; ++i)
	{
		sum += data[i];
	}

	return (data[4] == sum) && (data[1] < 10) && (data[3] < 10);
}
#endif //C_SW_DHT11


#if C_SW_DS18B20
/* Get water temperature from DS18B20 functions */
void SetupDS18B20()
{
	dS18b20.begin();
	dS18b20.setResolution(DS18B20_TEMPERATURE_RESOLUTION_BIT);
}

float GetTemperatureDS18B20()
{
	dS18b20.requestTemperatures();
	return dS18b20.getTempCByIndex(0);
}
#endif //C_SW_DS18B20


#if C_SW_EXT_RTC
//External RTC functions

bool InitializeExtRtc()
{
	bool isSuccess = true;

	//Initialize CTR1, 2 registers
	i2c.beginTransmission(RTC_I2C_ADDR);
	i2c.write(RTC_REG_CTR1);
	i2c.write(0x00); //Write to RTC_REG_CTR1.
	i2c.write(0x00); //Write to RTC_REG_CTR2
	uint8 result = i2c.endTransmission();
	if (result != SUCCESS)
	{
		char cbuf[64];
		snprintf(cbuf, sizeof(cbuf), "ERROR: i2c.endTransmission() for ctr1, 2 ret %d", result);
		SerialUSB.println(cbuf);
		isSuccess = false;
	}

	//Initialize Frequency, timer registors
	i2c.beginTransmission(RTC_I2C_ADDR);
	i2c.write(RTC_REG_CLKO_FREQ);
	i2c.write(0x00); //Write to RTC_REG_CLKO_FREQ
	i2c.write(0x00); //Write to RTC_REG_TIMER_CTR
	i2c.write(0x00); //Write to RTC_REG_TIMER

	result = i2c.endTransmission();
	if (result != SUCCESS)
	{
		char cbuf[64];
		snprintf(cbuf, sizeof(cbuf), "ERROR: i2c.endTransmission() for freq, timer ret %d", result);
		SerialUSB.println(cbuf);
		isSuccess = false;
	}

	return isSuccess;
}

bool SetExtRtcTime(const tm& current_time)
{
	{
		char cbuf[64];
		snprintf(cbuf, sizeof(cbuf), "INFO: SetExtRtcTime : %s", asctime(&current_time));
		SerialUSB.println(cbuf);
	}

	i2c.beginTransmission(RTC_I2C_ADDR);
	i2c.write(RTC_REG_SEC);

	const uint8 sec_to_reg = TranslateTimeToRegValueForExtRtc(current_time.tm_sec);
	i2c.write(sec_to_reg); //Write to RTC_REG_SEC

	const uint8 min_to_reg = TranslateTimeToRegValueForExtRtc(current_time.tm_min);
	i2c.write(min_to_reg); //Write to RTC_REG_MIN

	const uint8 hour_to_reg = TranslateTimeToRegValueForExtRtc(current_time.tm_hour);
	i2c.write(hour_to_reg); //Write to RTC_REG_HOUR

	const uint8 day_to_reg = TranslateTimeToRegValueForExtRtc(current_time.tm_mday);
	i2c.write(day_to_reg); //Write to RTC_REG_DAYS

	const uint8 weekday_to_reg = TranslateTimeToRegValueForExtRtc(current_time.tm_wday);
	i2c.write(weekday_to_reg); //Write to RTC_REG_WEEK

	const uint8 month_to_reg = TranslateTimeToRegValueForExtRtc(current_time.tm_mon);
	i2c.write(month_to_reg); //Write to RTC_REG_MONTH

	const uint8 year_to_reg = TranslateTimeToRegValueForExtRtc(current_time.tm_year);
	i2c.write(year_to_reg); //Write to RTC_REG_YEAR

	i2c.write(0x00); //Write to RTC_REG_MIN_ALR
	i2c.write(0x00); //Write to RTC_REG_HOUR_ALR
	i2c.write(0x00); //Write to RTC_REG_DAY_ALR
	i2c.write(0x00); //Write to RTC_REG_WEEK_ALR

	i2c.write(0x00); //Write to RTC_REG_CLKO_FREQ

	i2c.write(0x00); //Write to RTC_REG_TIMER_CTR
	i2c.write(0x00); //Write to RTC_REG_TIMER

	uint8 result = i2c.endTransmission();
	if (result != SUCCESS)
	{
		char cbuf[64];
		snprintf(cbuf, sizeof(cbuf), "ERROR: i2c.endTransmission() ret %d", result);
		SerialUSB.println(cbuf);
		return false;
	}

	return true;
}

bool GetExtRtcTime(tm& current_time)
{
	i2c.beginTransmission(RTC_I2C_ADDR);
	i2c.write(RTC_REG_SEC);
	uint8 result = i2c.endTransmission();
	if (result != SUCCESS)
	{
		char cbuf[64];
		snprintf(cbuf, sizeof(cbuf), "ERROR: i2c.endTransmission() to write addr ret %d", result);
		SerialUSB.println(cbuf);
		return false;
	}

	result = i2c.requestFrom(RTC_I2C_ADDR, 7);
	if (result != 7)
	{
		char cbuf[64];
		snprintf(cbuf, sizeof(cbuf), "ERROR: i2c.requestFrom(7) ret %d", result);
		SerialUSB.println(cbuf);
		return false;
	}
	   
	const uint8 reg_sec = i2c.read();
	const uint8 reg_min = i2c.read();
	const uint8 reg_hour = i2c.read();
	const uint8 reg_day = i2c.read();
	const uint8 reg_weekday = i2c.read();
	const uint8 reg_month = i2c.read();
	const uint8 reg_year = i2c.read();

	current_time.tm_sec = TranslateRegValueToTimeForExtRtc(reg_sec);
	current_time.tm_min = TranslateRegValueToTimeForExtRtc(reg_min);
	current_time.tm_hour = TranslateRegValueToTimeForExtRtc(reg_hour);
	current_time.tm_mday = TranslateRegValueToTimeForExtRtc(reg_day);
	current_time.tm_wday = TranslateRegValueToTimeForExtRtc(reg_weekday);
	current_time.tm_mon = TranslateRegValueToTimeForExtRtc(reg_month);
	current_time.tm_year = TranslateRegValueToTimeForExtRtc(reg_year);
}

uint8 TranslateTimeToRegValueForExtRtc(uint32 time)
{
	return static_cast<uint8>(time / 10) << 4 | static_cast<uint8>(time % 10);
}

uint32 TranslateRegValueToTimeForExtRtc(uint8 regv)
{
	return 10 * (regv >> 4) + (regv & 0x0F);
}

bool SetWakeupAlarmToExtRTC(time_t wakeup_time)
{
	struct tm tm_waketime = { 0 };
	gmtime_r(&wakeup_time, &tm_waketime);
	
	{
		char cbuf[64];
		snprintf(cbuf, sizeof(cbuf), "INFO: SetWakeupAlarmToExtRTC : %s", asctime(&tm_waketime));
		SerialUSB.println(cbuf);
	}

	//Set alarm time
	i2c.beginTransmission(RTC_I2C_ADDR);
	i2c.write(RTC_REG_MIN_ALR);
	const uint8 min_to_reg = TranslateTimeToRegValueForExtRtc(tm_waketime.tm_min);
	i2c.write(min_to_reg); //Write to RTC_REG_MIN
	i2c.write(0x80);
	i2c.write(0x80);
	i2c.write(0x80);
	uint8 result = i2c.endTransmission();
	if (result != SUCCESS)
	{
		char cbuf[64];
		snprintf(cbuf, sizeof(cbuf), "ERROR: i2c.endTransmission() for set time ret %d", result);
		SerialUSB.println(cbuf);
		return false;
	}

	//Enable Alarm
	i2c.beginTransmission(RTC_I2C_ADDR);
	i2c.write(RTC_REG_CTR2);
	i2c.write(0x02);
	result = i2c.endTransmission();
	if (result != SUCCESS)
	{
		char cbuf[64];
		snprintf(cbuf, sizeof(cbuf), "ERROR: i2c.endTransmission() for enable alarm ret %d", result);
		SerialUSB.println(cbuf);
		return false;
	}

	return true;
}
#endif //C_SW_EXT_RTC

#if C_SW_MS5540C

bool SetupMs5540c()
{
	//Set AF of pins for MS5540C
	////SCLK from B3
	gpio_set_af_mode(GPIOA, 5, 0);
	gpio_set_af_mode(GPIOB, 3, 5);
	////MCLK by pwm from B4
	gpio_set_af_mode(GPIOB, 4, 2);
	////OE signal from A4, C7
	gpio_set_af_mode(GPIOA, 4, 0);
	pinMode(OE_PIN_FOR_MS5540C_AIR, OUTPUT);
	gpio_set_af_mode(GPIOC, 7, 0);
	pinMode(OE_PIN_FOR_MS5540C_WATER, OUTPUT);

	ms5540cSpi.begin(SPI_281_250KHZ, MSBFIRST, SPI_MODE0);

	if (!MakeAdcClockToMs5540c())
	{
		SerialUSB.println("ERROR: MakeAdcClockToMs5540c");
		return false;
	}

	GetMs5540cCalibrationValues(MS5540C_AIR);
	GetMs5540cCalibrationValues(MS5540C_WATER);

	return true;
}

void EnableMs5540c(MS5540C_SENSOR_ID sensor_id)
{
	if (sensor_id == MS5540C_AIR)
	{
		digitalWrite(OE_PIN_FOR_MS5540C_AIR, 0);
		digitalWrite(OE_PIN_FOR_MS5540C_WATER, 1);
	}
	else if (sensor_id == MS5540C_WATER)
	{
		digitalWrite(OE_PIN_FOR_MS5540C_AIR, 1);
		digitalWrite(OE_PIN_FOR_MS5540C_WATER, 0);
	}
	else
	{
		digitalWrite(OE_PIN_FOR_MS5540C_AIR, 1);
		digitalWrite(OE_PIN_FOR_MS5540C_AIR, 1);
	}
}
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

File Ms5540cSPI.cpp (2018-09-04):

/******************************************************************************
 * The MIT License
 *
 * Copyright (c) 2010 Perry Hung.
 *
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
 * THE SOFTWARE IS PROVIDED "AS IS", WITHOUT WARRANTY OF ANY KIND,
 * EXPRESS OR IMPLIED, INCLUDING BUT NOT LIMITED TO THE WARRANTIES OF
 * MERCHANTABILITY, FITNESS FOR A PARTICULAR PURPOSE AND
 * NONINFRINGEMENT. IN NO EVENT SHALL THE AUTHORS OR COPYRIGHT HOLDERS
 * BE LIABLE FOR ANY CLAIM, DAMAGES OR OTHER LIABILITY, WHETHER IN AN
 * ACTION OF CONTRACT, TORT OR OTHERWISE, ARISING FROM, OUT OF OR IN
 * CONNECTION WITH THE SOFTWARE OR THE USE OR OTHER DEALINGS IN THE
 * SOFTWARE.
 *****************************************************************************/

/**
 * @author Marti Bolivar <mbolivar@leaflabs.com>
 * @brief Wirish SPI implementation.
 */
#include <stdio.h>
#include "Ms5540cSPI.h"

#include "timer.h"
#include "util.h"
#include "rcc.h"

#include "wirish.h"
#include "boards.h"

struct spi_pins {
    int8 nss;
    int8 sck;
    int8 miso;
    int8 mosi;
};

static const spi_pins* dev_to_spi_pins(spi_dev *dev);

static void enable_device(spi_dev *dev,
                          bool as_master,
                          SPIFrequency frequency,
                          spi_cfg_flag endianness,
                          spi_mode mode);

//Reset SPI1 pin for MS5540C
#undef BOARD_SPI1_NSS_PIN
#undef BOARD_SPI1_SCK_PIN
#undef BOARD_SPI1_MISO_PIN
#undef BOARD_SPI1_MOSI_PIN
#define BOARD_SPI1_NSS_PIN      -1
#define BOARD_SPI1_MOSI_PIN     Port2Pin('A', 7)
#define BOARD_SPI1_MISO_PIN     Port2Pin('A', 6)
#define BOARD_SPI1_SCK_PIN      Port2Pin('B', 3)

static const spi_pins board_spi_pins[] __FLASH__ = {
    {BOARD_SPI1_NSS_PIN,
     BOARD_SPI1_SCK_PIN,
     BOARD_SPI1_MISO_PIN,
     BOARD_SPI1_MOSI_PIN},
#ifdef BOARD_SPI2_NSS_PIN
	{BOARD_SPI2_NSS_PIN,
     BOARD_SPI2_SCK_PIN,
     BOARD_SPI2_MISO_PIN,
     BOARD_SPI2_MOSI_PIN},
#endif
#ifdef STM32_HIGH_DENSITY
    {BOARD_SPI3B_NSS_PIN,
     BOARD_SPI3B_SCK_PIN,
     BOARD_SPI3B_MISO_PIN,
     BOARD_SPI3B_MOSI_PIN},
#endif
#ifdef STM32F4
    {BOARD_SPI3B_NSS_PIN,
     BOARD_SPI3B_SCK_PIN,
     BOARD_SPI3B_MISO_PIN,
     BOARD_SPI3B_MOSI_PIN},
#endif
};


/*
 * Constructor
 */

Ms5540cSPI::Ms5540cSPI(uint32 spi_num) {
    switch (spi_num) {
    case 1:
        this->spi_d = SPI1;
        break;
    case 2:
        this->spi_d = SPI2;
        break;
#ifdef STM32_HIGH_DENSITY
    case 3:
        this->spi_d = SPI3;
        break;
#endif
#ifdef STM32F4
//    case 4:
//        this->spi_d = SPI4;
//        break;
#endif
    default:
        ASSERT(0);
    }
}

/*
 * Set up/tear down
 */

void Ms5540cSPI::begin(SPIFrequency frequency, uint32 bitOrder, uint32 mode) {
    if (mode >= 4) {
        ASSERT(0);
        return;
    }
    spi_cfg_flag end = bitOrder == MSBFIRST ? SPI_FRAME_MSB : SPI_FRAME_LSB;
    spi_mode m = (spi_mode)mode;
    enable_device(this->spi_d, true, frequency, end, m);
}

void Ms5540cSPI::begin(void) {
    this->begin(SPI_1_125MHZ, MSBFIRST, 0);
}

void Ms5540cSPI::beginSlave(uint32 bitOrder, uint32 mode) {
    if (mode >= 4) {
        ASSERT(0);
        return;
    }
    spi_cfg_flag end = bitOrder == MSBFIRST ? SPI_FRAME_MSB : SPI_FRAME_LSB;
    spi_mode m = (spi_mode)mode;
    enable_device(this->spi_d, false, (SPIFrequency)0, end, m);
}

void Ms5540cSPI::beginSlave(void) {
    this->beginSlave(MSBFIRST, 0);
}


/*
void Ms5540cSPI::beginTransaction(uint8_t pin, SPISettings settings)
{
//    this->begin(settings.clock, settings.bitOrder, settings.dataMode);
    this->begin(SPI_1_125MHZ, settings.bitOrder, settings.dataMode);
}
*/

void Ms5540cSPI::end(void) {
    if (!spi_is_enabled(this->spi_d)) {
        return;
    }

    // Follows RM0008's sequence for disabling a SPI in master/slave
    // full duplex mode.
    while (spi_is_rx_nonempty(this->spi_d)) {
        // FIXME [0.1.0] remove this once you have an interrupt based driver
        volatile uint16 rx __attribute__((unused)) = spi_rx_reg(this->spi_d);
    }
    while (!spi_is_tx_empty(this->spi_d))
        ;
    while (spi_is_busy(this->spi_d))
        ;
    spi_peripheral_disable(this->spi_d);
}

/*
 * I/O
 */

uint8 Ms5540cSPI::read(void) {
    uint8 buf[1];
    this->read(buf, 1);
    return buf[0];
}

void Ms5540cSPI::read(uint8 *buf, uint32 len) {
    uint32 rxed = 0;
    while (rxed < len) {
        while (!spi_is_rx_nonempty(this->spi_d))
            ;
        buf[rxed++] = (uint8)spi_rx_reg(this->spi_d);
    }
}

#if 0
void Ms5540cSPI::readMaster(uint8 *buf, uint32 len) {
    uint32 rxed = 0;
    while (rxed < len) {
		spi_tx_reg(this->spi_d, 0xff);
        while (!spi_is_rx_nonempty(this->spi_d))
            ;
        buf[rxed++] = (uint8)spi_rx_reg(this->spi_d);
		buf[rxed++] = this->spi_d->regs->DR;
    }
}
#endif
void Ms5540cSPI::readMaster(uint8 *buf, uint32 len) {
	spi_reg_map *r = this->spi_d->regs;
    uint32 rxed = 0;
    while (rxed < len) {
		r->DR = 0xff;
        while (!(r->SR & SPI_SR_RXNE))
            ;
		buf[rxed++] = r->DR;
    }
}


void Ms5540cSPI::waitReady() {
	while (!spi_is_rx_nonempty(this->spi_d))
		;
}

void Ms5540cSPI::write(uint8 byte) {
    this->write(&byte, 1);
}

void Ms5540cSPI::write(const uint8 *data, uint32 length) {
    uint32 txed = 0;
    while (txed < length) {
        txed += spi_tx(this->spi_d, data + txed, length - txed);
    }
}

uint8 Ms5540cSPI::transfer(uint8 byte) {
    this->write(byte);
    return this->read();
}

/*
 * Pin accessors
 */

uint8 Ms5540cSPI::misoPin(void) {
    return dev_to_spi_pins(this->spi_d)->miso;
}

uint8 Ms5540cSPI::mosiPin(void) {
    return dev_to_spi_pins(this->spi_d)->mosi;
}

uint8 Ms5540cSPI::sckPin(void) {
    return dev_to_spi_pins(this->spi_d)->sck;
}

uint8 Ms5540cSPI::nssPin(void) {
    return dev_to_spi_pins(this->spi_d)->nss;
}

/*
 * Deprecated functions
 */

uint8 Ms5540cSPI::send(uint8 data) {
    uint8 buf[] = {data};
    return this->send(buf, 1);
}

#if 1	
uint8 Ms5540cSPI::send(const uint8 *buf, uint32 len) {
    uint32 txed = 0;
    uint8 ret = 0;
    while (txed < len) {
        this->write(buf[txed++]);
        ret = this->read();
    }
    return ret;
}
#else
// this does not work for an unknown reason
uint8 Ms5540cSPI::send(const uint8 *buf, uint32 len) {
	volatile uint32 *dr = &(this->spi_d->regs->DR);
	volatile uint32 *sr = &(this->spi_d->regs->SR);
    uint32 txed = 0;
	uint32 rx=0;
    while (txed < len) {
        //while (!(*sr & SPI_SR_TXE))
        //    ;
		//*dr = buf[txed++];
		this->write(buf[txed++]);

        while (!(*sr & SPI_SR_RXNE))
			;
		rx = *dr;
		//rx = this->read();
    }

	return rx;
}
#endif

uint8 Ms5540cSPI::recv(void) {
    return this->read();
}

/*
 * Auxiliary functions
 */

static void configure_gpios(spi_dev *dev, bool as_master);
static spi_baud_rate determine_baud_rate(spi_dev *dev, SPIFrequency freq);
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

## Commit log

2018-08-09 Add initial ino file with function to read temperature and humidity and send these to serial and ambient
2018-08-10 Fix some bugs and pass tests
    [SensorToAmbient.ino]
2018-08-23 Add 1st fzz file
    [SensorToAmbient_breadboard_design.fzz]
2018-08-23 Fix a little
    [SensorToAmbient_breadboard_design.fzz]
2018-08-25 First success to get temperature
2018-08-26 Add compile switch C_SW_LTE
2018-08-26 Add compile switch C_SW_AMBIENT
2018-08-26 Add compile switch C_SW_DHT11
2018-08-26 Add compile switch C_SW_DS18B20
2018-08-26 Add compile switch C_SW_GPS
2018-08-26 First success to get battery boltage
2018-08-26 Fix a bug that serial print doesn't work in the case only C_SW_BATTERY_V is enabled
    [SensorToAmbient.ino]
2018-08-26 Enable all compile switches
2018-09-01 Commit intermediate ( First complete to implement with software SPI class )
2018-09-02 Commit intermediate ( Debugging spi to ms5540c )
2018-09-02 Make Ms5540CSPI class for SPI communication to MS5540C with specific pins
2018-09-02 Implement function to make ADC clock for MS5540C by pwm that can be enabled by compile switch
2018-09-04 First success to get pressure and temperature
2018-09-15 Commit intermediate ( Adding new parts )
    [SensorToAmbient_breadboard_design.fzz]
2018-09-17 Update substrate design of fritzing
    [SensorToAmbient_breadboard_design.fzz]
2018-09-21 Add LED and second batteries
    [SensorToAmbient_breadboard_design.fzz]
2018-09-21 Add initial files of KiCAD
    [SensorToAmbient.kicad_pcb, SensorToAmbient.sch]
2018-09-21 Move files of Fritzing to folder 'Fritzing'
    [SensorToAmbient_breadboard_design.fzz]
2018-09-21 Commit intermediate (Making schematics)
    [SensorToAmbient.sch]
2018-09-22 Complete to wire
    [SensorToAmbient.sch, SensorToAmbient_breadboard_design.fzz]
2018-09-22 Assign foorprints to symbols
    [SensorToAmbient.sch]
2018-09-22 Commit intermediate (Making pcb design)
    [SensorToAmbient.sch]
2018-09-23 Making boardedge and spacer holes
    [SensorToAmbient.kicad_pcb]
2018-09-23 Complete of footprint layout before first wiring work
    [SensorToAmbient.kicad_pcb, SensorToAmbient.sch]
2018-09-24 Commit intermediate (before revice part layout for wiring)
    [SensorToAmbient.kicad_pcb, SensorToAmbient.sch]
2018-09-24 Commit intermediate (Revice schematic for pcb wiring)
    [SensorToAmbient.kicad_pcb, SensorToAmbient.sch]
2018-09-24 Commit intermediate (Remaining wire is only one GND)
    [SensorToAmbient.kicad_pcb, SensorToAmbient.sch]
2018-09-24 First comple of wiring
    [SensorToAmbient.kicad_pcb, SensorToAmbient.sch]
2018-09-24 Fix DRC errors
    [SensorToAmbient.kicad_pcb, SensorToAmbient.sch]
2018-09-24 Make ground plane
    [SensorToAmbient.kicad_pcb, SensorToAmbient.sch]
2018-09-24 Add silks
    [SensorToAmbient.kicad_pcb]
2018-09-24 Add zakojifarm logo on pcb
    [SensorToAmbient.kicad_pcb]
2018-09-26 Add a 3d model of grove connector
    [GroveConnector_110990037.f3d, GroveConnector_110990037.step, SensorToAmbient.kicad_pcb]
2018-09-26 Improve 3d model of grove connector
    [GroveConnector_110990037.f3d, SensorToAmbient.kicad_pcb]
2018-09-27 Add a 3D model of RTC for pcb footprint
    [SensorToAmbient.kicad_pcb]
2018-09-27 Add a 3D model of DCDC for pcb footprint
    [RTC_8564NB_Akidsuki.f3d]
2018-09-27 Fix commit leak files
    [SensorToAmbient.kicad_pcb]
2018-09-28 Commit intermediate (Delete Wil LTE outline from pcb)
    [SensorToAmbient.kicad_pcb]
2018-09-28 Add step files for export pcb step for 3DCAD
    [DIP-14_W7.62mm.step, PowerBoost500.step, RTC-8564NB_Akidsuki.step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]
2018-09-28 Add pcb 3D model file for fusion360
    [SensorToAmbientPcb.f3d]
2018-10-05 Update SensorToAmbient pcb and add wiolte board pcb
    [WioLTE.step, WioLTEBoard.f3d]
2018-10-05 Add housing 3d model
2018-10-05 Get two Ms5540c sensor values and calcurate water level
2018-10-06 Commit intermediate (Add items for power controll)
    [SensorToAmbient.sch]
2018-10-06 Commit intermediate (Making double-side board)
    [SensorToAmbient.kicad_pcb, SensorToAmbient.sch]
2018-10-07 Complete making new double-side board
    [SensorToAmbient.kicad_pcb, SensorToAmbient.sch]
2018-10-09 Commit intermediate (Debugging non-stable i2c)
2018-10-09 First complete of external rtc handling (But use workaround for I2C)
    [SensorToAmbient.ino]
2018-10-11 Commit intermediate (Complete of fixing schmatic)
    [SensorToAmbient.kicad_pcb, SensorToAmbient.sch]
2018-10-11 Commit intermediate (Changing footprints of resistor and diode to SMD)
    [SensorToAmbient.kicad_pcb, SensorToAmbient.sch]
2018-10-11 Commit intermediate ( First complete of updating pcb )
    [SensorToAmbient.kicad_pcb, SensorToAmbient.sch]
2018-10-11 Complete fixing pcb board
    [SensorToAmbient.kicad_pcb]
2018-10-12 Complete running with only battery
    [SensorToAmbient.kicad_pcb, SensorToAmbient.sch]
2018-10-12 Correct resistor const on pcb
    [SensorToAmbient.kicad_pcb, SensorToAmbient.sch]
2018-10-13 Update silks on pcb for order
    [SensorToAmbient.kicad_pcb]
2018-10-14 First succeed at compiling abount managing led codes
2018-10-15 Fix bugs finded in basic tests to manage led function
    [SensorToAmbient.ino]
2018-10-15 Remove workaround for I2c initialization
    [SensorToAmbient.ino]
2018-10-16 Move position of whole pcb
    [SensorToAmbient.kicad_pcb]
2018-10-16 Adjust pcb design for order
    - Change a resistor for A4 power to diode
    - Fit connectors on the inside of pcb edge
    - Align wires
    [SensorToAmbient.kicad_pcb, SensorToAmbient.sch]
2018-10-16 Connect all GND pins of grove connectors to battery GND
    [SensorToAmbient.kicad_pcb, SensorToAmbient.sch]

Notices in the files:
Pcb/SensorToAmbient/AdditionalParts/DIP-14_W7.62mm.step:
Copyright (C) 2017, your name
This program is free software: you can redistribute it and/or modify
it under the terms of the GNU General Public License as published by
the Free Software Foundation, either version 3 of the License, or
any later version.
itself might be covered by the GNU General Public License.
